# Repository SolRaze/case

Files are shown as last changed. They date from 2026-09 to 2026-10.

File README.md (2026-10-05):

case

parametric iphone case for any phone in ref/iphone | 3d-printable stl | apple dimensional drawing data for every product on the accessories drawings page

layout
- case.py | the case: geometry, checks, stl export, previews, command line
- phone.py | a phone from ref/iphone | rules.py and rules.json | which knobs build, and the guideline limits
- styles.json | styles as named knob sets
- ref/ | drawing data per product, one json per model, index in ref/README.md
- laptop/ | MS-16W1 mainboard measured off a pegboard, findings in laptop/README.md
- previews/ | every build seen from the back | tools/ | drawing fetch and reading, phone body check, readme writer
- web/ | memory card browser: every phone with a case, modelled from its drawing | phones.py reads phone.py and rules.json at dev and build

run
- `python case.py` 17e, every style | `python case.py magsafe frame` | `--phone 16 --phone air` | `--all`
- `--check` no output files | `--no-png` stl only | stl to out/, not committed
- `python rules.py` phone x style table | `--write` refresh the invalid table | `--verify`
- `python tools/fetch.py` drawings and guidelines into pdf/, not committed
- `python tools/readme.py` rewrite the readmes
- web/ `npm install` | `npm run phones` writes web/phones.json, `npm run glb` packs out/ stl into web/public/glb | `npm run dev`

styles
- base | the template every phone gets: flat outside, 1.0 mm back skin under lengthwise channels on the phone side that run out into the camera window and through the bottom wall; every button a flexure key with a ridge to find it by; one chamfered bottom opening from speaker to speaker with room for a cable boot; 1.5 mm corner bumpers
- case | full case: a window per button, fitted camera ring, full back
- slot | one button slot per side, fitted camera, full back
- magsafe | pockets for the ADG 42.1 magnet array, glued in from the phone side; action and side buttons as flexure keys where the phone has them
- sides | top and bottom walls open between the corners
- corners | held at the four corners, full back, walls open between them and rounded at the ends
- frame | back kept as an 8 mm band round the edge, the camera ring on an island swept into it
- edge | edge only: the walls and a 1.5 mm lip of back round the edge, the camera open
- plateframe | frame with a rebate for the swap-in back plate
- plate | 1 mm swap-in back plate for plateframe, dropped in from the phone side and held by the phone
- spine | 1.5 mm band and a full-width strip across the fitted camera ring carrying slider rails
- slider | lens cover for spine, printed flat on its outside face, slides down clear of the lens and flash keepouts
- leather | printed core for a 0.6 mm leather skin glued over the full back and walls: 0.95 mm walls, 1.4 mm back, 1.8 and 2.0 with the skin on; camera ring and a 1.5 mm rim band stand flush with the skin and cover its edges
- cig | snap clip for one unlit cigarette along the right edge of the back; PETG softens near 80 C
- corner | bottom-right corner only, 45 mm of each edge: squircle corner, USB-C edge and speaker group, a fit test that prints in minutes
- ribs | full case, ribbed back: 1.2 mm between 1.2 mm ribs on a 10 mm grid, 2.0 at the ribs
- ribcorner | the corner coupon with a ribbed back: 1.2 mm between 1.2 mm ribs on a 10 mm grid, 2.0 at the ribs
- flip | full case carrying a front cover on a 3DS-style hinge along the left edge: two end knuckles, stop shelves for the cover open flat at 180, 1.5 mm corner bumpers
- cover | 2 mm front cover for flip, its barrel runs between the case's knuckles on a 1.75 filament pin

knobs
- BUTTONS | default "windows" | "windows" "slot"
- KEYS | default [] | button names; names a phone lacks are dropped
- CLOSED | default [] | button names, none shared with KEYS
- BACK_BAND | default null | null (full back) or mm of back kept round the edge
- RING | default true | false true
- PLATE | default false | false true
- WALLS | default "full" | "full" "sides" "corners"
- MAGSAFE | default null | null "ring" "open"
- SLIDER | default false | false true
- CIG | default false | false true
- COUPON | default null | null or mm of each edge kept round the bottom-right corner
- FLIP | default false | false true
- RIBS | default null | null (solid back) or mm pocketed out of the back between ribs
- RIB_SIDE | default "out" | "out" "in"
- BUMPER | default null | null or mm the outside bulges out round each corner
- LEATHER | default null | null or mm of leather glued over the outside
- PORT | default "split" | "split" "merged"
- VENT | default false | false true

design
- The outside is one rounded shape: a 1.55 mm wall rolling into the back over 3.0 mm, a 0.8 mm round on the front rim, and the rim opening flared 0.4 mm.
- The camera opening hugs every lens and the plateau they stand on, 1.2 mm out; flash and mic outside it get their own hole. A full-width plateau opens the top of the back, its top corners and rim kept.
- The camera ring stands 1.0 mm past the lens: a flat 1.5 mm top, its outside rounded; the camera and flash holes chamfer 0.4 mm at their outside edge, every other opening in the back rounds out 0.75 mm.
- A banded back keeps the camera ring on an island swept out to the band, every inside corner filleted at 6 mm, so each opening is one curve.
- Open walls end in a 5 mm round into the back and a 2 mm round over the rim top.
- Button windows and port openings are obround; a flexure key hinges toward the larger gap to the next button. The receiver gets a shallow dip in the top rim that eases back up over 4 mm each side.
- Styles only change knobs, so every style shares this shape.

rules | build skips a phone and style that break one, and says which
- The slider and MagSafe don't mix: the rails run down to y -52 and the charger's top edge sits at -45.
- The magnets and the charger hole need the full back round them.
- A back plate needs a banded back to sit in.
- Keys need side walls, so they don't work with corner-only walls.
- A button is either a key or closed over, never both.
- Ribs pocket the full back; the magnets need it solid.
- The hinge knuckles stand on the left wall, so the flip cover needs it.
- A leather skin needs a plain outside: full walls, no ribs, bumpers or MagSafe magnets.
- Leaving the camera without a ring needs a banded back, and no slider or leather skin.
- Vents run out of the inner channels, so they need ribs on the phone side.
- Phones whose sheet has no corner profile can't be built. Ruled out: 5s.
- The slider can't cover a full-width camera plateau. Fits only se-2-3, 12, 16e, 17e.
- The slider needs room for its right rail beside the camera. Fits only se-2-3, 12, 16e, 17e.
- The cigarette clip needs a phone long enough to hold it. Ruled out: 12-mini, 13-mini.
- The flip cover's top knuckle starts 1 mm past the corner arc and must clear the left buttons. Ruled out: 12-mini, 12, 12-pro, 13-mini, se-2-3.

limits | from the apple accessory design guidelines and the phone sheets, checked on every build
- Any exposed glass stays at least 0.85 mm, ideally 1.0, off a flat table; the rim and camera ring stand 1.0 proud. (ADG 5.1.1)
- The back of the case is 2.0 mm thick, under the 2.1 each phone sheet allows (5.0 on the SE). (note 8 on every iPhone sheet)
- The bottom wall is 1.55 mm, under the 1.8 mm docks and cables allow. (ADG 5.1.3)
- MagSafe magnets sit 0.85 mm from the outside face at most. (ADG 42.1 fig 42-3)
- Every lens and flash light cone is cut clear, with the fit clearance added. (ADG 5.7.1 and each sheet's keepout cones)
- The USB-C connector keepout is cut through the bottom wall, with the fit clearance added. (each sheet, ADG 5.1.2.3)
- Speaker and mic openings reach 2.0 mm past the port, with a 45 degree chamfer outside and a 0.6 mm straight land. (ADG 5.2.3.1)
- The front rim reaches 0.5 mm over the phone's rolled edge: more than the 0.25 clearance so it holds the phone, and short of the glass edge at 1.05. (17e sheet, glass edge 1.05 in)

checks
- every build: closed mesh, one solid, glass gap >= 0.85 for front glass, lens cover, back glass
- 489 of 570 phone x style build and pass | the rest are in rules.json invalid

previews | from the back, grid in previews/README.md
- 5s | none, sheet has no corner profile
- [se-2-3](previews/README.md#se-2-3) | 17 styles
- [12-mini](previews/README.md#12-mini) | 14 styles
- [12](previews/README.md#12) | 17 styles
- [12-pro](previews/README.md#12-pro) | 15 styles
- [12-pro-max](previews/README.md#12-pro-max) | 17 styles
- [13-mini](previews/README.md#13-mini) | 14 styles
- [13](previews/README.md#13) | 17 styles
- [13-pro](previews/README.md#13-pro) | 17 styles
- [13-pro-max](previews/README.md#13-pro-max) | 17 styles
- [14](previews/README.md#14) | 17 styles
- [14-plus](previews/README.md#14-plus) | 17 styles
- [14-pro](previews/README.md#14-pro) | 17 styles
- [14-pro-max](previews/README.md#14-pro-max) | 17 styles
- [15](previews/README.md#15) | 17 styles
- [15-plus](previews/README.md#15-plus) | 17 styles
- [15-pro](previews/README.md#15-pro) | 17 styles
- [15-pro-max](previews/README.md#15-pro-max) | 17 styles
- [16](previews/README.md#16) | 17 styles
- [16-plus](previews/README.md#16-plus) | 17 styles
- [16e](previews/README.md#16e) | 19 styles
- [16-pro](previews/README.md#16-pro) | 17 styles
- [16-pro-max](previews/README.md#16-pro-max) | 17 styles
- [17](previews/README.md#17) | 17 styles
- [17e](previews/README.md#17e) | 19 styles
- [air](previews/README.md#air) | 17 styles
- [17-pro](previews/README.md#17-pro) | 17 styles
- [17-pro-max](previews/README.md#17-pro-max) | 17 styles
- [18-pro](previews/README.md#18-pro) | 17 styles
- [18-pro-max](previews/README.md#18-pro-max) | 17 styles

requirements
- `pip install -r requirements.txt` | blender's python module, numpy, pymupdf | libegl for headless previews

license mit

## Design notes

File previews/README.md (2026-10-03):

previews

one section per phone, every style that builds, seen from the back | python case.py writes them

se-2-3

| base | case | slot | magsafe | sides | corners | frame | edge | plateframe | plate | spine | slider | leather | cig | corner | ribs | ribcorner |
|---|---|---|---|---|---|---|---|---|---|---|---|---|---|---|---|---|
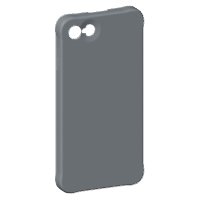
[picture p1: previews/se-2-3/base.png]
base
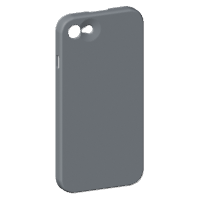
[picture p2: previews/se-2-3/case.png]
case
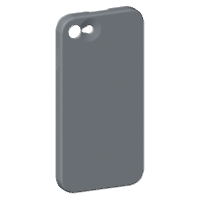
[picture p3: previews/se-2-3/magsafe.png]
magsafe
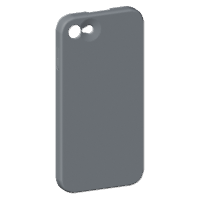
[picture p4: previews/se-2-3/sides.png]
sides
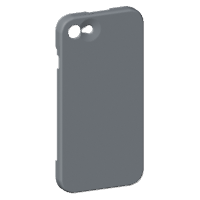
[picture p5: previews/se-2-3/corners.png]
corners
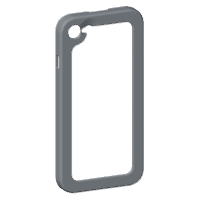
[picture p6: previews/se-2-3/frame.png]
frame
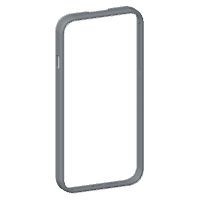
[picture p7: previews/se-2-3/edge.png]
edge
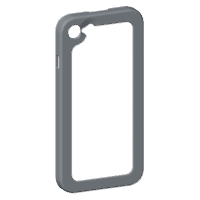
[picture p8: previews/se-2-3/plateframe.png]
plateframe
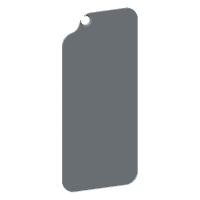
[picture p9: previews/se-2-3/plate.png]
plate
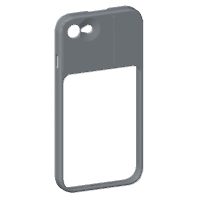
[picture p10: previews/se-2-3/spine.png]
spine
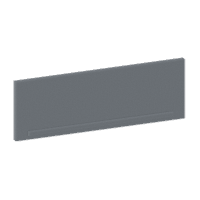
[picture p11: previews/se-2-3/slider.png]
slider
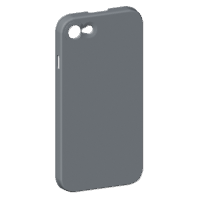
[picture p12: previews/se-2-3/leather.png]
leather
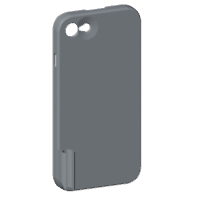
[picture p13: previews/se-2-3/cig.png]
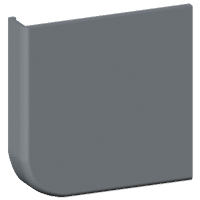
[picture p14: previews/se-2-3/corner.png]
corner
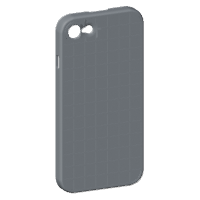
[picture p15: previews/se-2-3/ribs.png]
ribs
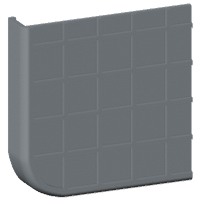
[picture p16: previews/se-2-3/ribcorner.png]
ribcorner
|  |  | slot |  |  |  |  |  |  |  |  |  |  |  |  |  |  |

12-mini

| base | case | slot | magsafe | sides | corners | frame | edge | plateframe | plate | leather | corner | ribs | ribcorner |
|---|---|---|---|---|---|---|---|---|---|---|---|---|---|
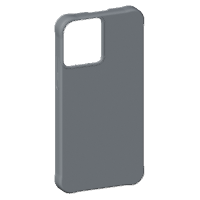
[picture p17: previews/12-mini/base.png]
base
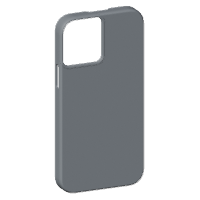
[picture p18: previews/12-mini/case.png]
case
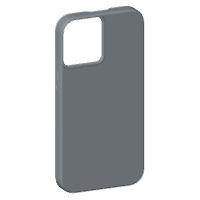
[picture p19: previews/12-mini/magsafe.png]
magsafe
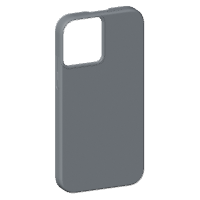
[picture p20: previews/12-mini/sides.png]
sides
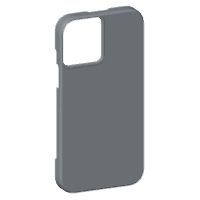
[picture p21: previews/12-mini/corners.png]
corners
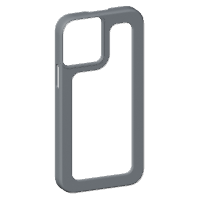
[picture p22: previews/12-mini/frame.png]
frame
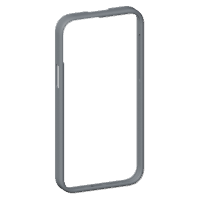
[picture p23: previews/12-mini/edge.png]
edge
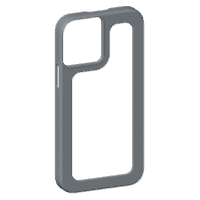
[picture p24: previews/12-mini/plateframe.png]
plateframe
|  |  | slot |  |  |  |  |  |  | plate | leather | corner | ribs | ribcorner |

12

| base | case | slot | magsafe | sides | corners | frame | edge | plateframe | plate | spine | slider | leather | cig | corner | ribs | ribcorner |
|---|---|---|---|---|---|---|---|---|---|---|---|---|---|---|---|---|
| base | case | slot | magsafe | sides | corners | frame | edge | plateframe | plate | spine | slider | leather | cig | corner | ribs | ribcorner |

12-pro

| base | case | slot | magsafe | sides | corners | frame | edge | plateframe | plate | leather | cig | corner | ribs | ribcorner |
|---|---|---|---|---|---|---|---|---|---|---|---|---|---|---|
| base | case | slot | magsafe | sides | corners | frame | edge | plateframe | plate | leather | cig | corner | ribs | ribcorner |

12-pro-max

| base | case | slot | magsafe | sides | corners | frame | edge | plateframe | plate | leather | cig | corner | ribs | ribcorner | flip | cover |
|---|---|---|---|---|---|---|---|---|---|---|---|---|---|---|---|---|
| base | case | slot | magsafe | sides | corners | frame | edge | plateframe | plate | leather | cig | corner | ribs | ribcorner | flip | cover |

13-mini

| base | case | slot | magsafe | sides | corners | frame | edge | plateframe | plate | leather | corner | ribs | ribcorner |
|---|---|---|---|---|---|---|---|---|---|---|---|---|---|
| base | case | slot | magsafe | sides | corners | frame | edge | plateframe | plate | leather | corner | ribs | ribcorner |

13

| base | case | slot | magsafe | sides | corners | frame | edge | plateframe | plate | leather | cig | corner | ribs | ribcorner | flip | cover |
|---|---|---|---|---|---|---|---|---|---|---|---|---|---|---|---|---|
| base | case | slot | magsafe | sides | corners | frame | edge | plateframe | plate | leather | cig | corner | ribs | ribcorner | flip | cover |

13-pro

| base | case | slot | magsafe | sides | corners | frame | edge | plateframe | plate | leather | cig | corner | ribs | ribcorner | flip | cover |
|---|---|---|---|---|---|---|---|---|---|---|---|---|---|---|---|---|
| base | case | slot | magsafe | sides | corners | frame | edge | plateframe | plate | leather | cig | corner | ribs | ribcorner | flip | cover |

13-pro-max

| base | case | slot | magsafe | sides | corners | frame | edge | plateframe | plate | leather | cig | corner | ribs | ribcorner | flip | cover |
|---|---|---|---|---|---|---|---|---|---|---|---|---|---|---|---|---|
| base | case | slot | magsafe | sides | corners | frame | edge | plateframe | plate | leather | cig | corner | ribs | ribcorner | flip | cover |

14

| base | case | slot | magsafe | sides | corners | frame | edge | plateframe | plate | leather | cig | corner | ribs | ribcorner | flip | cover |
|---|---|---|---|---|---|---|---|---|---|---|---|---|---|---|---|---|
| base | case | slot | magsafe | sides | corners | frame | edge | plateframe | plate | leather | cig | corner | ribs | ribcorner | flip | cover |

14-plus

| base | case | slot | magsafe | sides | corners | frame | edge | plateframe | plate | leather | cig | corner | ribs | ribcorner | flip | cover |
|---|---|---|---|---|---|---|---|---|---|---|---|---|---|---|---|---|
| base | case | slot | magsafe | sides | corners | frame | edge | plateframe | plate | leather | cig | corner | ribs | ribcorner | flip | cover |

14-pro

| base | case | slot | magsafe | sides | corners | frame | edge | plateframe | plate | leather | cig | corner | ribs | ribcorner | flip | cover |
|---|---|---|---|---|---|---|---|---|---|---|---|---|---|---|---|---|
| base | case | slot | magsafe | sides | corners | frame | edge | plateframe | plate | leather | cig | corner | ribs | ribcorner | flip | cover |

14-pro-max

| base | case | slot | magsafe | sides | corners | frame | edge | plateframe | plate | leather | cig | corner | ribs | ribcorner | flip | cover |
|---|---|---|---|---|---|---|---|---|---|---|---|---|---|---|---|---|
| base | case | slot | magsafe | sides | corners | frame | edge | plateframe | plate | leather | cig | corner | ribs | ribcorner | flip | cover |

15

| base | case | slot | magsafe | sides | corners | frame | edge | plateframe | plate | leather | cig | corner | ribs | ribcorner | flip | cover |
|---|---|---|---|---|---|---|---|---|---|---|---|---|---|---|---|---|
| base | case | slot | magsafe | sides | corners | frame | edge | plateframe | plate | leather | cig | corner | ribs | ribcorner | flip | cover |

15-plus

| base | case | slot | magsafe | sides | corners | frame | edge | plateframe | plate | leather | cig | corner | ribs | ribcorner | flip | cover |
|---|---|---|---|---|---|---|---|---|---|---|---|---|---|---|---|---|
| base | case | slot | magsafe | sides | corners | frame | edge | plateframe | plate | leather | cig | corner | ribs | ribcorner | flip | cover |

15-pro

| base | case | slot | magsafe | sides | corners | frame | edge | plateframe | plate | leather | cig | corner | ribs | ribcorner | flip | cover |
|---|---|---|---|---|---|---|---|---|---|---|---|---|---|---|---|---|
| base | case | slot | magsafe | sides | corners | frame | edge | plateframe | plate | leather | cig | corner | ribs | ribcorner | flip | cover |

15-pro-max

| base | case | slot | magsafe | sides | corners | frame | edge | plateframe | plate | leather | cig | corner | ribs | ribcorner | flip | cover |
|---|---|---|---|---|---|---|---|---|---|---|---|---|---|---|---|---|
| base | case | slot | magsafe | sides | corners | frame | edge | plateframe | plate | leather | cig | corner | ribs | ribcorner | flip | cover |

16

| base | case | slot | magsafe | sides | corners | frame | edge | plateframe | plate | leather | cig | corner | ribs | ribcorner | flip | cover |
|---|---|---|---|---|---|---|---|---|---|---|---|---|---|---|---|---|
| base | case | slot | magsafe | sides | corners | frame | edge | plateframe | plate | leather | cig | corner | ribs | ribcorner | flip | cover |

16-plus

| base | case | slot | magsafe | sides | corners | frame | edge | plateframe | plate | leather | cig | corner | ribs | ribcorner | flip | cover |
|---|---|---|---|---|---|---|---|---|---|---|---|---|---|---|---|---|
| base | case | slot | magsafe | sides | corners | frame | edge | plateframe | plate | leather | cig | corner | ribs | ribcorner | flip | cover |

16e

| base | case | slot | magsafe | sides | corners | frame | edge | plateframe | plate | spine | slider | leather | cig | corner | ribs | ribcorner | flip | cover |
|---|---|---|---|---|---|---|---|---|---|---|---|---|---|---|---|---|---|---|
| base | case | slot | magsafe | sides | corners | frame | edge | plateframe | plate | spine | slider | leather | cig | corner | ribs | ribcorner | flip | cover |

16-pro

| base | case | slot | magsafe | sides | corners | frame | edge | plateframe | plate | leather | cig | corner | ribs | ribcorner | flip | cover |
|---|---|---|---|---|---|---|---|---|---|---|---|---|---|---|---|---|
| base | case | slot | magsafe | sides | corners | frame | edge | plateframe | plate | leather | cig | corner | ribs | ribcorner | flip | cover |

16-pro-max

| base | case | slot | magsafe | sides | corners | frame | edge | plateframe | plate | leather | cig | corner | ribs | ribcorner | flip | cover |
|---|---|---|---|---|---|---|---|---|---|---|---|---|---|---|---|---|
| base | case | slot | magsafe | sides | corners | frame | edge | plateframe | plate | leather | cig | corner | ribs | ribcorner | flip | cover |

17

| base | case | slot | magsafe | sides | corners | frame | edge | plateframe | plate | leather | cig | corner | ribs | ribcorner | flip | cover |
|---|---|---|---|---|---|---|---|---|---|---|---|---|---|---|---|---|
| base | case | slot | magsafe | sides | corners | frame | edge | plateframe | plate | leather | cig | corner | ribs | ribcorner | flip | cover |

17e

| base | case | slot | magsafe | sides | corners | frame | edge | plateframe | plate | spine | slider | leather | cig | corner | ribs | ribcorner | flip | cover |
|---|---|---|---|---|---|---|---|---|---|---|---|---|---|---|---|---|---|---|
| base | case | slot | magsafe | sides | corners | frame | edge | plateframe | plate | spine | slider | leather | cig | corner | ribs | ribcorner | flip | cover |

air

| base | case | slot | magsafe | sides | corners | frame | edge | plateframe | plate | leather | cig | corner | ribs | ribcorner | flip | cover |
|---|---|---|---|---|---|---|---|---|---|---|---|---|---|---|---|---|
| base | case | slot | magsafe | sides | corners | frame | edge | plateframe | plate | leather | cig | corner | ribs | ribcorner | flip | cover |

17-pro

| base | case | slot | magsafe | sides | corners | frame | edge | plateframe | plate | leather | cig | corner | ribs | ribcorner | flip | cover |
|---|---|---|---|---|---|---|---|---|---|---|---|---|---|---|---|---|
| base | case | slot | magsafe | sides | corners | frame | edge | plateframe | plate | leather | cig | corner | ribs | ribcorner | flip | cover |

17-pro-max

| base | case | slot | magsafe | sides | corners | frame | edge | plateframe | plate | leather | cig | corner | ribs | ribcorner | flip | cover |
|---|---|---|---|---|---|---|---|---|---|---|---|---|---|---|---|---|
| base | case | slot | magsafe | sides | corners | frame | edge | plateframe | plate | leather | cig | corner | ribs | ribcorner | flip | cover |

18-pro

| base | case | slot | magsafe | sides | corners | frame | edge | plateframe | plate | leather | cig | corner | ribs | ribcorner | flip | cover |
|---|---|---|---|---|---|---|---|---|---|---|---|---|---|---|---|---|
| base | case | slot | magsafe | sides | corners | frame | edge | plateframe | plate | leather | cig | corner | ribs | ribcorner | flip | cover |

18-pro-max

| base | case | slot | magsafe | sides | corners | frame | edge | plateframe | plate | leather | cig | corner | ribs | ribcorner | flip | cover |
|---|---|---|---|---|---|---|---|---|---|---|---|---|---|---|---|---|
| base | case | slot | magsafe | sides | corners | frame | edge | plateframe | plate | leather | cig | corner | ribs | ribcorner | flip | cover |

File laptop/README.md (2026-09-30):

laptop

MS-16W1 mainboard | GF65 Thin 10SER | measured from two photos on a SKÅDIS pegboard, not calipered | 1 unit = 1 mm

files
- ms-16w1.json | board outline, stack heights, ports, fans, shield, accuracy per value
- board-ortho.json | panel frame, 10 fitted edges, 51 shield openings, heatsink-side extents

findings
- length 352.2 | heatsink face to port-edge PCB | +/-3
- width 156.9 | PCB edge to PCB edge | +/-1.5
- heatsink overhang past PCB 3.5
- M.2 protrusion 74.0 | two 2280 cards past the PCB edge, unsupported, the enclosure carries their screw ends
- shield 306.1 x 116.4 | face 11.4 +/-1.6 off the panel
- stack 8.0 heatsink side | 3.0 shield side | PCB 1.2 assumed | derived, not measured
- grid fit | front 52 slots 1.66 px rms | oblique 34 slots 2.00 px rms
- heatsink edge worst residual | +Y 0.7 px | -Y 0.6 | +X 1.1 | -X 5.3, noisy from the ports, uses the +X line direction
- SO-DIMM 70.4 against 69.6 nominal
- rerun reproduces every value | true-scale images byte-identical to the stored ones

open
- GPU fan PAAD06015SL N433 missing from the bay
- unconfirmed PCB step about 6.7 x 11.5 near local (159.6, -51.1), not in the outline
- caliper check of length, width and stack

source
- skadis-measure.py in the cad repo, from the two source photos | photos and images not in this repo

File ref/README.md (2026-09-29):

ref

apple dimensional drawings, one json per model, grouped by family | 1 unit = 1 mm | null = not dimensioned on the sheet
- pdfs from the source urls, fetched by tools/fetch.py into pdf/, not committed
- iphone/sizes.json | main-sheet summary of every iphone, what the case loader reads
- each json lists what was read by eye under unverified

airpods

| model | file | sheet date | source |
|---|---|---|---|
| AirPods 4 | [airpods-4.json](airpods/airpods-4.json) | 2024-09-19 | https://developer.apple.com/download/files/accessories/dimensional-drawings/airpods-4.pdf |
| Charging Case (USB-C) for AirPods 4 and Wireless Charging Case (USB-C) for AirPods 4 (ANC) | [charging-case-4.json](airpods/charging-case-4.json) | 2024-09-19 | https://developer.apple.com/download/files/accessories/dimensional-drawings/wireless-charging-case-usb-c-for-airpods-4.pdf |
| AirPods Max | [max.json](airpods/max.json) | 2024-09-19 | https://developer.apple.com/download/files/accessories/dimensional-drawings/airpods-max.pdf |
| MagSafe Charging Case (USB-C) for AirPods Pro (2nd generation) | [magsafe-case-usb-c-pro-2.json](airpods/magsafe-case-usb-c-pro-2.json) | 2023-10-10 | https://developer.apple.com/download/files/accessories/dimensional-drawings/magsafe-charging-case-usb-c-for-airpods-pro-2nd-generation.pdf |
| AirPods Pro (2nd generation) | [airpods-pro-2.json](airpods/airpods-pro-2.json) | 2022-09-21 | https://developer.apple.com/download/files/accessories/dimensional-drawings/airpods-pro-2nd-generation.pdf |
| MagSafe Charging Case for AirPods Pro (2nd generation) | [magsafe-case-pro-2.json](airpods/magsafe-case-pro-2.json) | 2022-09-21 | https://developer.apple.com/download/files/accessories/dimensional-drawings/magsafe-charging-case-for-airpods-pro-2nd-generation.pdf |
| AirPods (2nd generation) | [airpods-2.json](airpods/airpods-2.json) | 2022-04-26 | https://developer.apple.com/download/files/accessories/dimensional-drawings/airpods-2nd-generation.pdf |
| AirPods (3rd generation) | [airpods-3.json](airpods/airpods-3.json) | 2022-04-26 | https://developer.apple.com/download/files/accessories/dimensional-drawings/airpods-3rd-generation.pdf |
| MagSafe Charging Case for AirPods (3rd generation) | [magsafe-case-3.json](airpods/magsafe-case-3.json) | 2022-04-26 | https://developer.apple.com/download/files/accessories/dimensional-drawings/magsafe-charging-case-for-airpods-3rd-generation.pdf |
| AirPods 5 | [airpods-5.json](airpods/airpods-5.json) | - | https://developer.apple.com/download/files/accessories/dimensional-drawings/airpods-5.pdf |
| AirPods Pro 3 | [airpods-pro-3.json](airpods/airpods-pro-3.json) | - | https://developer.apple.com/download/files/accessories/dimensional-drawings/airpods-pro-3.pdf |
| MagSafe Charging Case for AirPods Pro 3 | [magsafe-case-pro-3.json](airpods/magsafe-case-pro-3.json) | - | https://developer.apple.com/download/files/accessories/dimensional-drawings/magsafe-charging-case-for-airpods-pro-3.pdf |

ipad

| model | file | sheet date | source |
|---|---|---|---|
| iPad mini (A17 Pro) | [mini-a17-pro.json](ipad/mini-a17-pro.json) | 2024-10-21 | https://developer.apple.com/download/files/accessories/dimensional-drawings/ipad-mini-a17-pro.pdf |
| iPad Air 11-inch (M2) | [air-11-inch-m2.json](ipad/air-11-inch-m2.json) | 2024-05-13 | https://developer.apple.com/download/files/accessories/dimensional-drawings/ipad-air-11-inch-m2.pdf |
| iPad Air 13-inch (M2) | [air-13-inch-m2.json](ipad/air-13-inch-m2.json) | 2024-05-13 | https://developer.apple.com/download/files/accessories/dimensional-drawings/ipad-air-13-inch-m2.pdf |
| iPad Pro 11-inch (M4) | [pro-11-inch-m4.json](ipad/pro-11-inch-m4.json) | 2024-05-13 | https://developer.apple.com/download/files/accessories/dimensional-drawings/ipad-pro-11-inch-m4.pdf |
| iPad Pro 13-inch (M4) | [pro-13-inch-m4.json](ipad/pro-13-inch-m4.json) | 2024-05-13 | https://developer.apple.com/download/files/accessories/dimensional-drawings/ipad-pro-13-inch-m4.pdf |
| iPad (10th generation) | [10th-generation.json](ipad/10th-generation.json) | 2022-10-26 | https://developer.apple.com/download/files/accessories/dimensional-drawings/ipad-10th-generation.pdf |
| iPad Pro 11-inch (4th generation) | [pro-11-inch-4th-generation.json](ipad/pro-11-inch-4th-generation.json) | 2022-10-26 | https://developer.apple.com/download/files/accessories/dimensional-drawings/ipad-pro-11-inch-4th-generation.pdf |
| iPad Pro 12.9-inch (6th generation) | [pro-12.9-inch-6th-generation.json](ipad/pro-12.9-inch-6th-generation.json) | 2022-10-26 | https://developer.apple.com/download/files/accessories/dimensional-drawings/ipad-pro-12.9-inch-6th-generation.pdf |
| iPad Air (5th generation) | [air-5th-generation.json](ipad/air-5th-generation.json) | 2022-04-26 | https://developer.apple.com/download/files/accessories/dimensional-drawings/ipad-air-5th-generation.pdf |
| iPad Air (4th generation) | [air-4th-generation.json](ipad/air-4th-generation.json) | 2020-10-16 | https://developer.apple.com/download/files/accessories/dimensional-drawings/ipad-air-4th-generation.pdf |
| iPad (A16) | [a16.json](ipad/a16.json) | - | https://developer.apple.com/download/files/accessories/dimensional-drawings/ipad-a16.pdf |
| iPad Air 11-inch (M3) | [air-11-inch-m3.json](ipad/air-11-inch-m3.json) | - | https://developer.apple.com/download/files/accessories/dimensional-drawings/ipad-air-11-inch-m3.pdf |
| iPad Air 11-inch (M4) | [air-11-inch-m4.json](ipad/air-11-inch-m4.json) | - | https://developer.apple.com/download/files/accessories/dimensional-drawings/ipad-air-11-inch-m4.pdf |
| iPad Air 13-inch (M3) | [air-13-inch-m3.json](ipad/air-13-inch-m3.json) | - | https://developer.apple.com/download/files/accessories/dimensional-drawings/ipad-air-13-inch-m3.pdf |
| iPad Air 13-inch (M4) | [air-13-inch-m4.json](ipad/air-13-inch-m4.json) | - | https://developer.apple.com/download/files/accessories/dimensional-drawings/ipad-air-13-inch-m4.pdf |
| iPad Pro 11-inch (M5) | [pro-11-inch-m5.json](ipad/pro-11-inch-m5.json) | - | https://developer.apple.com/download/files/accessories/dimensional-drawings/ipad-pro-11-inch-m5.pdf |
| iPad Pro 13-inch (M5) | [pro-13-inch-m5.json](ipad/pro-13-inch-m5.json) | - | https://developer.apple.com/download/files/accessories/dimensional-drawings/ipad-pro-13-inch-m5.pdf |

iphone

| model | file | sheet date | source |
|---|---|---|---|
| iPhone 18 Pro Max | [18-pro-max.json](iphone/18-pro-max.json) | 2026-09-09 | https://developer.apple.com/download/files/accessories/dimensional-drawings/iphone-18-pro-max.pdf |
| iPhone 18 Pro | [18-pro.json](iphone/18-pro.json) | 2026-09-09 | https://developer.apple.com/download/files/accessories/dimensional-drawings/iphone-18-pro.pdf |
| iPhone 17e | [17e.json](iphone/17e.json) | 2026-03-09 | https://developer.apple.com/download/files/accessories/dimensional-drawings/iphone-17e.pdf |
| iPhone 17 Pro Max | [17-pro-max.json](iphone/17-pro-max.json) | 2025-09-09 | https://developer.apple.com/download/files/accessories/dimensional-drawings/iphone-17-pro-max.pdf |
| iPhone 17 Pro | [17-pro.json](iphone/17-pro.json) | 2025-09-09 | https://developer.apple.com/download/files/accessories/dimensional-drawings/iphone-17-pro.pdf |
| iPhone 17 | [17.json](iphone/17.json) | 2025-09-09 | https://developer.apple.com/download/files/accessories/dimensional-drawings/iphone-17.pdf |
| iPhone Air | [air.json](iphone/air.json) | 2025-09-09 | https://developer.apple.com/download/files/accessories/dimensional-drawings/iphone-air.pdf |
| iPhone 16e | [16e.json](iphone/16e.json) | 2025-03-17 | https://developer.apple.com/download/files/accessories/dimensional-drawings/iphone-16e.pdf |
| iPhone 16 Plus | [16-plus.json](iphone/16-plus.json) | 2024-09-19 | https://developer.apple.com/download/files/accessories/dimensional-drawings/iphone-16-plus.pdf |
| iPhone 16 Pro Max | [16-pro-max.json](iphone/16-pro-max.json) | 2024-09-19 | https://developer.apple.com/download/files/accessories/dimensional-drawings/iphone-16-pro-max.pdf |
| iPhone 16 Pro | [16-pro.json](iphone/16-pro.json) | 2024-09-19 | https://developer.apple.com/download/files/accessories/dimensional-drawings/iphone-16-pro.pdf |
| iPhone 16 | [16.json](iphone/16.json) | 2024-09-19 | https://developer.apple.com/download/files/accessories/dimensional-drawings/iphone-16.pdf |
| iPhone 15 Plus | [15-plus.json](iphone/15-plus.json) | 2023-10-10 | https://developer.apple.com/download/files/accessories/dimensional-drawings/iphone-15-plus.pdf |
| iPhone 15 Pro Max | [15-pro-max.json](iphone/15-pro-max.json) | 2023-10-10 | https://developer.apple.com/download/files/accessories/dimensional-drawings/iphone-15-pro-max.pdf |
| iPhone 15 Pro | [15-pro.json](iphone/15-pro.json) | 2023-10-10 | https://developer.apple.com/download/files/accessories/dimensional-drawings/iphone-15-pro.pdf |
| iPhone 15 | [15.json](iphone/15.json) | 2023-10-10 | https://developer.apple.com/download/files/accessories/dimensional-drawings/iphone-15.pdf |
| iPhone 14 Plus | [14-plus.json](iphone/14-plus.json) | 2022-09-21 | https://developer.apple.com/download/files/accessories/dimensional-drawings/iphone-14-plus.pdf |
| iPhone 14 Pro Max | [14-pro-max.json](iphone/14-pro-max.json) | 2022-09-21 | https://developer.apple.com/download/files/accessories/dimensional-drawings/iphone-14-pro-max.pdf |
| iPhone 14 Pro | [14-pro.json](iphone/14-pro.json) | 2022-09-21 | https://developer.apple.com/download/files/accessories/dimensional-drawings/iphone-14-pro.pdf |
| iPhone 14 | [14.json](iphone/14.json) | 2022-09-21 | https://developer.apple.com/download/files/accessories/dimensional-drawings/iphone-14.pdf |
| iPhone SE (3rd generation) | [se-3.json](iphone/se-3.json) | 2022-04-26 | https://developer.apple.com/download/files/accessories/dimensional-drawings/iphone-se-3rd-generation.pdf |

mac

| model | file | sheet date | source |
|---|---|---|---|
| MacBook Neo | [macbook-neo.json](mac/macbook-neo.json) | - | https://developer.apple.com/download/files/accessories/dimensional-drawings/macbook-neo.pdf |

magsafe

| model | file | sheet date | source |
|---|---|---|---|
| Apple MagSafe Charger (1 m) and (2 m) | [charger-1m-2m.json](magsafe/charger-1m-2m.json) | 2024-09-19 | https://developer.apple.com/download/files/accessories/dimensional-drawings/apple-magsafe-charger-1-m-and-apple-magsafe-charger-2-m.pdf |
| Apple MagSafe Charger (A2140) | [charger.json](magsafe/charger.json) | 2024-09-19 | https://developer.apple.com/download/files/accessories/dimensional-drawings/apple-magsafe-charger.pdf |

tv

| model | file | sheet date | source |
|---|---|---|---|
| Apple TV 4K (3rd generation) | [apple-tv-4k-3rd-generation.json](tv/apple-tv-4k-3rd-generation.json) | 2022-10-26 | https://developer.apple.com/download/files/accessories/dimensional-drawings/apple-tv-4k-3rd-generation.pdf |
| Siri Remote (3rd generation) | [siri-remote-3rd-generation.json](tv/siri-remote-3rd-generation.json) | 2022-10-26 | https://developer.apple.com/download/files/accessories/dimensional-drawings/siri-remote-3rd-generation.pdf |

vision

| model | file | sheet date | source |
|---|---|---|---|
| Apple Vision Pro Audio Strap | [audio-strap.json](vision/audio-strap.json) | 2024-05-13 | https://developer.apple.com/download/files/accessories/dimensional-drawings/apple-vision-pro-audio-strap.pdf |
| Apple Vision Pro Battery | [battery.json](vision/battery.json) | 2024-05-13 | https://developer.apple.com/download/files/accessories/dimensional-drawings/apple-vision-pro-battery.pdf |
| Apple Vision Pro | [vision-pro.json](vision/vision-pro.json) | 2024-05-13 | https://developer.apple.com/download/files/accessories/dimensional-drawings/apple-vision-pro.pdf |
| ZEISS Optical Inserts for Apple Vision Pro | [zeiss-optical-inserts.json](vision/zeiss-optical-inserts.json) | 2024-05-13 | https://developer.apple.com/download/files/accessories/dimensional-drawings/zeiss-optical-inserts.pdf |

watch

| model | file | sheet date | source |
|---|---|---|---|
| Apple Watch Series 10, 42 mm | [series-10-42mm.json](watch/series-10-42mm.json) | 2024-09-19 | https://developer.apple.com/download/files/accessories/dimensional-drawings/apple-watch-series-10-42mm.pdf |
| Apple Watch Series 10, 46 mm | [series-10-46mm.json](watch/series-10-46mm.json) | 2024-09-19 | https://developer.apple.com/download/files/accessories/dimensional-drawings/apple-watch-series-10-46mm.pdf |
| Apple Watch Series 9, 41 mm | [series-9-41mm.json](watch/series-9-41mm.json) | 2023-10-10 | https://developer.apple.com/download/files/accessories/dimensional-drawings/apple-watch-series-9-41mm.pdf |
| Apple Watch Series 9, 45 mm | [series-9-45mm.json](watch/series-9-45mm.json) | 2023-10-10 | https://developer.apple.com/download/files/accessories/dimensional-drawings/apple-watch-series-9-45mm.pdf |
| Apple Watch Ultra 2 | [ultra-2.json](watch/ultra-2.json) | 2023-10-10 | https://developer.apple.com/download/files/accessories/dimensional-drawings/apple-watch-ultra-2.pdf |
| Apple Watch Series 8, 41 mm | [series-8-41mm.json](watch/series-8-41mm.json) | 2022-09-21 | https://developer.apple.com/download/files/accessories/dimensional-drawings/apple-watch-series-8-41mm.pdf |
| Apple Watch Series 8, 45 mm | [series-8-45mm.json](watch/series-8-45mm.json) | 2022-09-21 | https://developer.apple.com/download/files/accessories/dimensional-drawings/apple-watch-series-8-45mm.pdf |
| Apple Watch Ultra | [ultra.json](watch/ultra.json) | 2022-09-21 | https://developer.apple.com/download/files/accessories/dimensional-drawings/apple-watch-ultra.pdf |
| Apple Watch SE 3, 40 mm | [se-3-40mm.json](watch/se-3-40mm.json) | - | https://developer.apple.com/download/files/accessories/dimensional-drawings/apple-watch-se-3-40mm.pdf |
| Apple Watch SE 3, 44 mm | [se-3-44mm.json](watch/se-3-44mm.json) | - | https://developer.apple.com/download/files/accessories/dimensional-drawings/apple-watch-se-3-44mm.pdf |
| Apple Watch Series 11, 42 mm | [series-11-42mm.json](watch/series-11-42mm.json) | - | https://developer.apple.com/download/files/accessories/dimensional-drawings/apple-watch-series-11-42mm.pdf |
| Apple Watch Series 11, 46 mm | [series-11-46mm.json](watch/series-11-46mm.json) | - | https://developer.apple.com/download/files/accessories/dimensional-drawings/apple-watch-series-11-46mm.pdf |
| Apple Watch Series 12, 42 mm | [series-12-42mm.json](watch/series-12-42mm.json) | - | https://developer.apple.com/download/files/accessories/dimensional-drawings/apple-watch-series-12-42mm.pdf |
| Apple Watch Series 12, 46 mm | [series-12-46mm.json](watch/series-12-46mm.json) | - | https://developer.apple.com/download/files/accessories/dimensional-drawings/apple-watch-series-12-46mm.pdf |
| Apple Watch Ultra 3 | [ultra-3.json](watch/ultra-3.json) | - | https://developer.apple.com/download/files/accessories/dimensional-drawings/apple-watch-ultra-3.pdf |
| Apple Watch Ultra 4 | [ultra-4.json](watch/ultra-4.json) | - | https://developer.apple.com/download/files/accessories/dimensional-drawings/apple-watch-ultra-4.pdf |

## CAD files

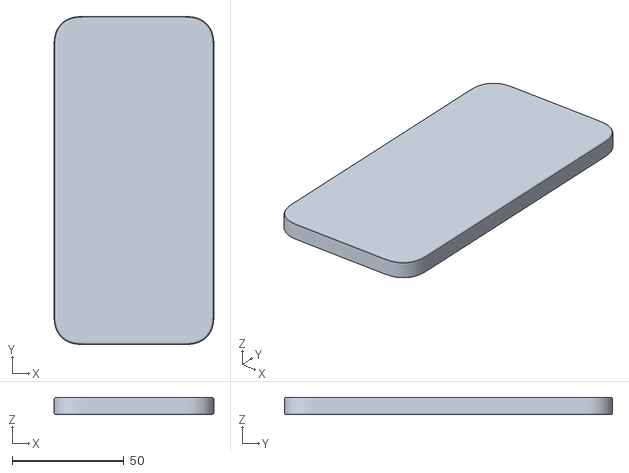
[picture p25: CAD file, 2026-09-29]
ref/iphone/17e-body.stl
71.5 x 146.7 x 7.80

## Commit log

2026-09-29 initial commit case
    [iphone-17e-body.stl]
2026-09-29 add watch 12 42mm ref
2026-09-29 add watch 12 46mm ref
2026-09-29 ref by family
    [17e-body.stl]
2026-09-29 add watch 11 42mm ref
2026-09-29 add watch 11 46mm ref
2026-09-29 add watch se 3 40mm ref
2026-09-29 add watch se 3 44mm ref
2026-09-29 add airpods pro 3 case ref
2026-09-29 phone knob in case
2026-09-29 blender reads case.py
2026-09-29 add magsafe charger ref
2026-09-29 add magsafe charger 2m ref
2026-09-29 add watch series 10 42mm ref
2026-09-29 add watch series 10 46mm ref
2026-09-29 add airpods 4 case ref
2026-09-29 add vision pro strap ref
2026-09-29 add vision pro battery ref
2026-09-29 add zeiss inserts ref
2026-09-29 zeiss magnet polarity
2026-09-29 add watch series 9 41mm ref
2026-09-29 add watch series 9 45mm ref
2026-09-29 add magsafe case pro 2 ref
2026-09-29 add magsafe case pro 2 lightning
2026-09-29 add watch series 8 41mm ref
2026-09-29 add watch series 8 45mm ref
2026-09-29 add magsafe case 3 ref
2026-09-29 blender print source
2026-09-29 softer case shape
2026-09-29 round lens ring
2026-09-29 lens ring previews
2026-09-29 even rib pitch
2026-09-30 laptop board findings
2026-10-02 flip cover hinge
2026-10-02 fitted camera again
2026-10-02 k3 lens ring
2026-10-06 locked phones, worn case
2026-10-06 full name, case on
2026-10-06 core case only
